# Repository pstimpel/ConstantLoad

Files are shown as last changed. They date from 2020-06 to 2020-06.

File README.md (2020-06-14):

# Adjustable Constant Load, Constant Current and Constant Power

Based on the work of GreatScott https://www.instructables.com/id/DIY-Adjustable-Constant-Load-Current-Power/

## Improvements compared to GreatScotts original version

* better handling of the rotary encoder
* the original project was a little bit dangerous. If the Arduino boots or resets during probing, the mosfet was fully open for about 2 seconds. A 10k resistor from PWM pin to ground solved this
* the glas fuse was replaced by a polyfuse, 0.9A
* added temperature control using a 1wire DS18B20 sensor. Includes shutdown of the whole device if temperature alarm was triggered
* added software based over current protection and over power protection in source code
* switched to INA219 sensor for measuring voltage and current, makes voltage divider and ACS712 obsolete. This sensor can handle up to 26V and 3.2A - however, we are using much lower values
* Added a 3d printed case to the repository. 
* Since we do not have to rely on the low resolution of the Arduino ADC anymore, we can measure both current and voltage with more precision and resolution.

IMAGE ALT TEXT HERE (https://www.youtube.com/watch?v=1KW89nFb7pY)

## BOM, tools used by me

* Arduino Nano
* INA219 breakout
* MicroUSB breakout (I am powering my 5V benchstuff using MicroUSB, this is not needed if you supply 5V in another way)
* Mosfet IRFZ44N
* Mosfet driver IC TC4420, maybe 2x4 IC socket as well?
* some 2.54mm pinheaders
* some wires
* Resistors, 0.25W: 10R, 4k7, 10k
* Electrolytic capacitors, 10V: 22uF, 470uF
* Polyfuse 0.9A
* LCD 16x2, I2C
* Rotary Encoder
* Dupont cables female female
* 2 binding posts 4mm
* 1 switch SPST
* 1 heatsink, big enough to deal with the heat
* 5V power supply
* M4 screws to mount temperatur sensor and mosfet to the heatsink
* Solder stuff
* some basic tools like a screw driver, alan keys and so on
* M3.5 drill and M4 tap and die tool to add holes into the heatsink of not there already
* M4.5 drill to widen the hole in the TO220 case of the mosfet.

You should be able to source all parts from your top supplier for parts. At the moment the bill represents a value of less than 50 Euros, given you own all the tools already.

If you are using the 3D printed case I am providing in subfolder stl

* M3 screws to mount the housing parts to each other
* M2 screws to fix the LCD in its place
* a 3D printer and some filament of your choice
 
## Home of this project

https://github.com/pstimpel/ConstantLoad

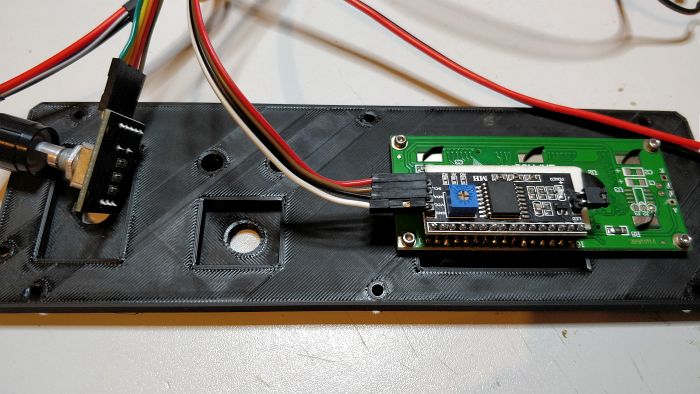
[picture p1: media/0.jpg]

 
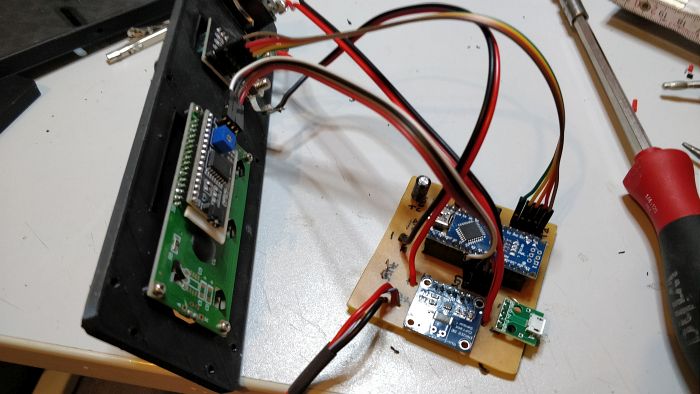
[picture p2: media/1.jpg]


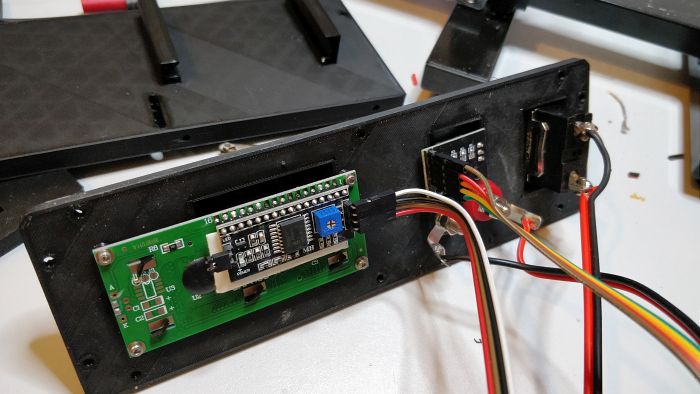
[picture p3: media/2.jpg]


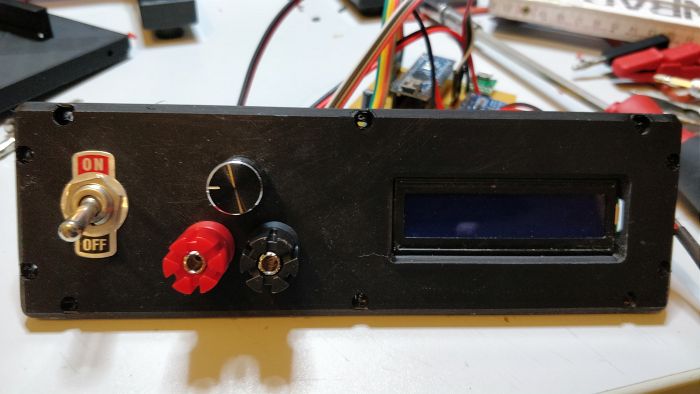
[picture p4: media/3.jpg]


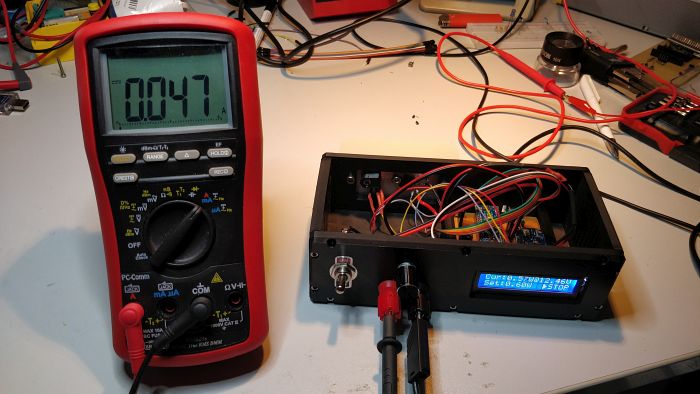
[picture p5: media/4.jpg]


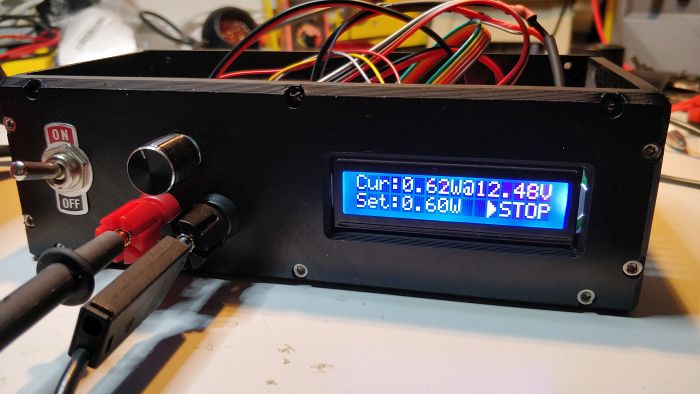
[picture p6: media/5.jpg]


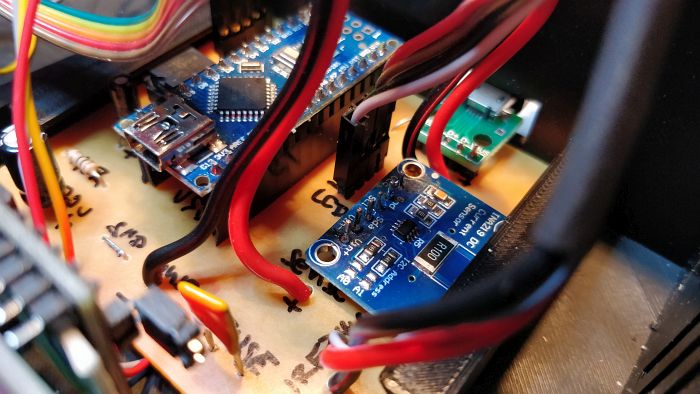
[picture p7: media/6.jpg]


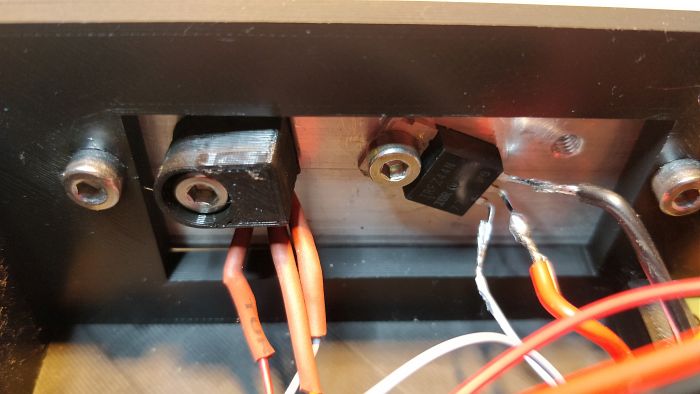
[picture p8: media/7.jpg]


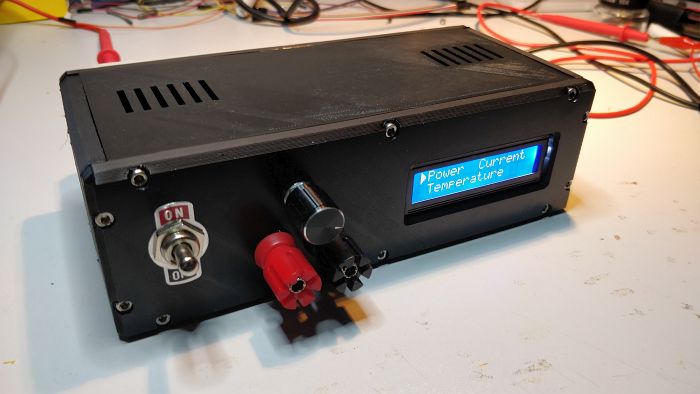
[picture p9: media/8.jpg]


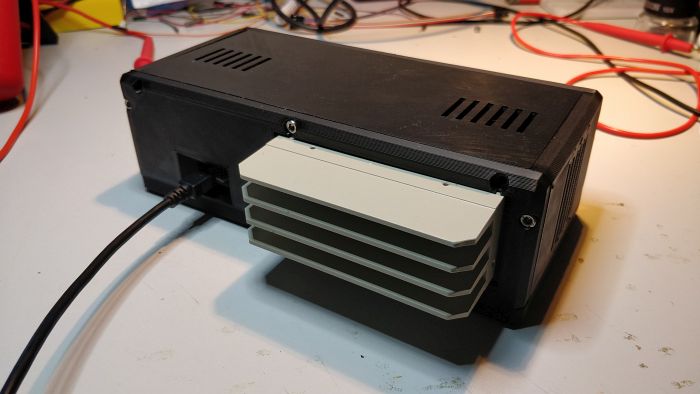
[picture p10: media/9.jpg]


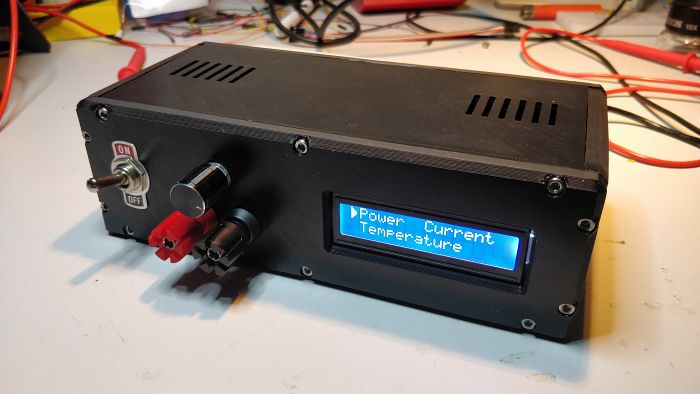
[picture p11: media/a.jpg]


## Build instructions

Just follow the guide by GreatScott. Different steps are:

1.) Use the circuit provided by me to take advantage of temperature control, some more security and the different sensor

2.) Use the Arduino sketch provided by me to take advantage of temperature control, some more security and the different sensor. On top you will find the use of this device a little bit easier. At least I do.

## 3D print instructions

There is nothing special. I used PLA, no supports needed. 3 shells and 10% infill did it. 

## Arduino Libraries

https://github.com/johnrickman/LiquidCrystal_I2C

https://github.com/adafruit/Adafruit_INA219

https://www.pjrc.com/teensy/td_libs_OneWire.html

https://github.com/milesburton/Arduino-Temperature-Control-Library

## How to use

Connect the device to 5V power source. Connect the circuit you want to "probe". Take care of plus and minus. Power the device on. Select the desired measuring method from the main menu. Current creates a constant current load, while Power creates a constant power load. Under Temperature you can monitor the temperature sensor and review the set temperature alarm threshold.

Once you select your Watts or Amperes and start the load mechanism, it might take a few seconds until the load starts consuming electrons. This is because the Arduino does probe step by step how much the mosfet should be open to turn the desired current into heat. This is a protection, do not attempt to speed up this process.

If one of the software protection measures was activated, the whole device will stop operation, including the mosfet. You have to turn off and on the device to restart operation. It is a good choice to clear the mistake that triggered the protection.

Since we use a polyfuse, the curcuit becomes cut once the fuse triggers due too much current. Just switch off the device and wait a few minutes so the fuse can cool down a bit. By cooling down, the fuse becomes operational again.

Be careful, the device does some overshooting once it tries to find the right mosfet balancing. This overshooting can cause quite "nice" spikes in the current consumption. Stay relaxed with raising your thresholds.

## Possible improvements

I would like to have a more smooth Rotary encoder use. It hops around sometimes. Maybe it is the cheap encoder I got, maybe there are better options to read the button press and encoder turns. 

I guess it is quite important to add more security features, like a working over voltage protection and over current protection based on hardware, not software. Right now we have over current protection and over power protection in software, only. Over voltage protection is not functional yet as well.

It should be possible to protect the device from wrong connected probing. If you turn around plus and minus of the circuit you want to put load on, strange things might happen. 

If the heatsink gets too hot, I would like to add a fan and some fan control, so the fan mounted to the heatsink could kick in and help with the cooling. We have plenty of options since we have our Arduino in the middle of our device. 

## Thanks to ...

GreatScott. His Youtube channel provides lots of insights and many cool projects. You should pay him a visit.

## Feedback

If you go for a build, I would like it very much to hear from you. Maybe you want to share pics of your device? You can find me at

https://twitter.com/PjotrS72

https://www.prusaprinters.org/social/2411-pstimpel/prints

https://www.thingiverse.com/pstimpel

## Finally...

I am providing this stuff as it is. I do not promise anything, and I am not responsible for any harm you might create or receive by following this manual or by using the methods and results described in this manual.

### Warning

High current / power can cause heat, and heat can cause injuries. Make sure you adapt the warnlevels on top of the Arduino sketch to your needs. Especially the temperature alarm threshold should be set below the melting temperature of your filament if you were going for the 3D printed case.

## License: 

https://creativecommons.org/licenses/by-nc-sa/4.0/

Most obvious limits of this license:
* You are not allowed to use this stuff for commercial purposes
* You can download, reupload and change the stuff, but have to release it under the same license again
* You have the mention the origin, like "Original by Peter Stimpel, https://github.com/pstimpel/ConstantLoad"

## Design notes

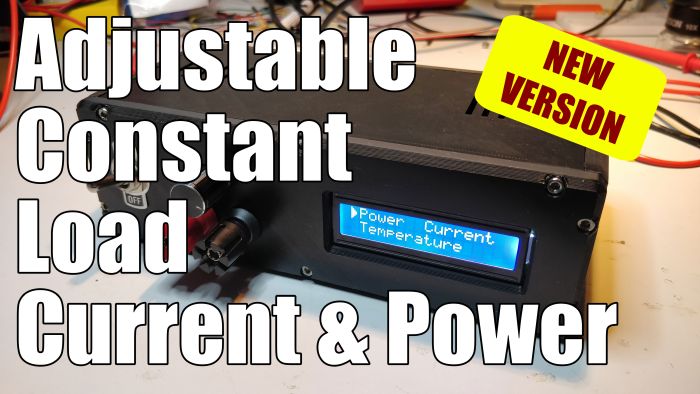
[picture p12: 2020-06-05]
media/title_16_9sm.jpg

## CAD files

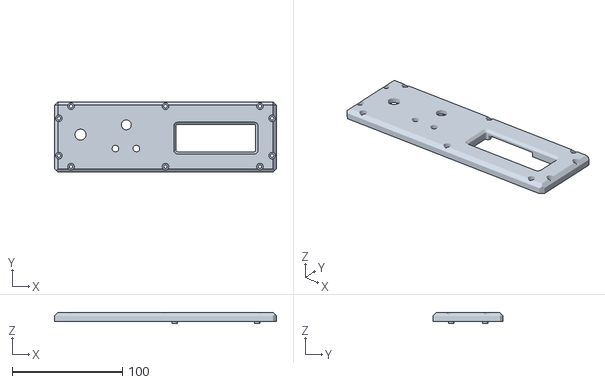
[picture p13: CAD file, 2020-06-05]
stl/Front.stl
201.5 x 63.8 x 10.0

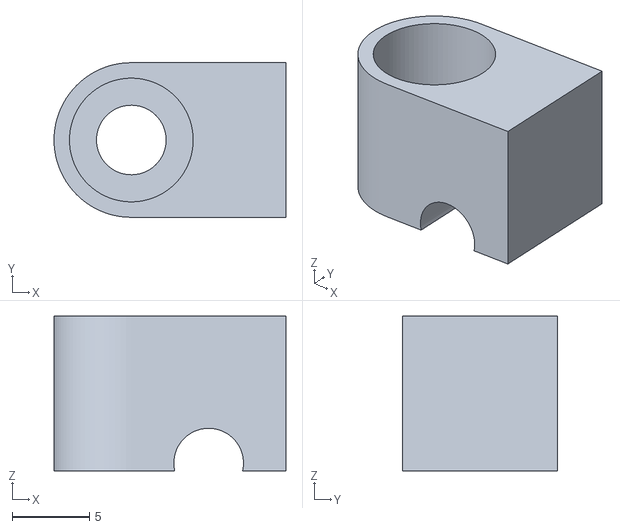
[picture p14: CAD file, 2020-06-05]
stl/Heatsensorclamp.stl
15.0 x 10.0 x 10.0

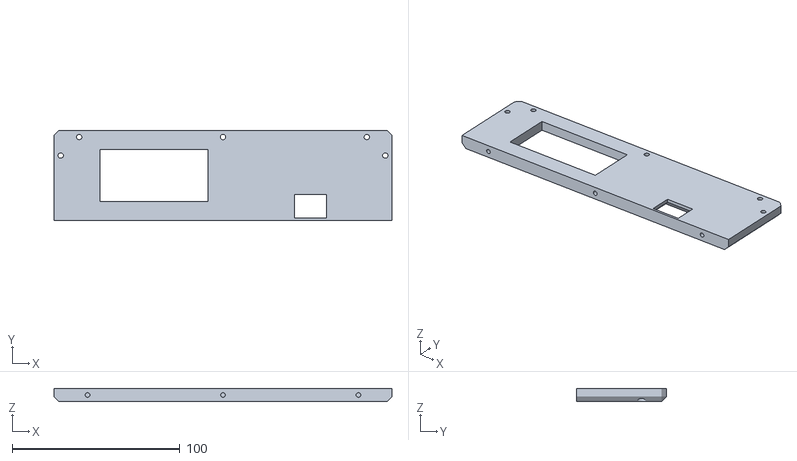
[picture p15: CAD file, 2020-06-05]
stl/Back.stl
201.5 x 53.8 x 8.00

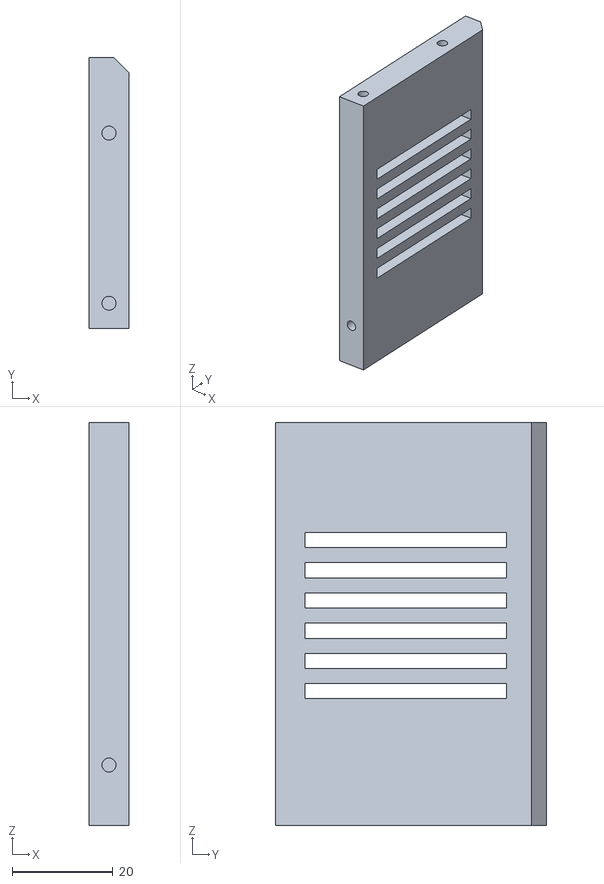
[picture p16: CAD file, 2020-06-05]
stl/Right.stl
8.00 x 53.8 x 80.0

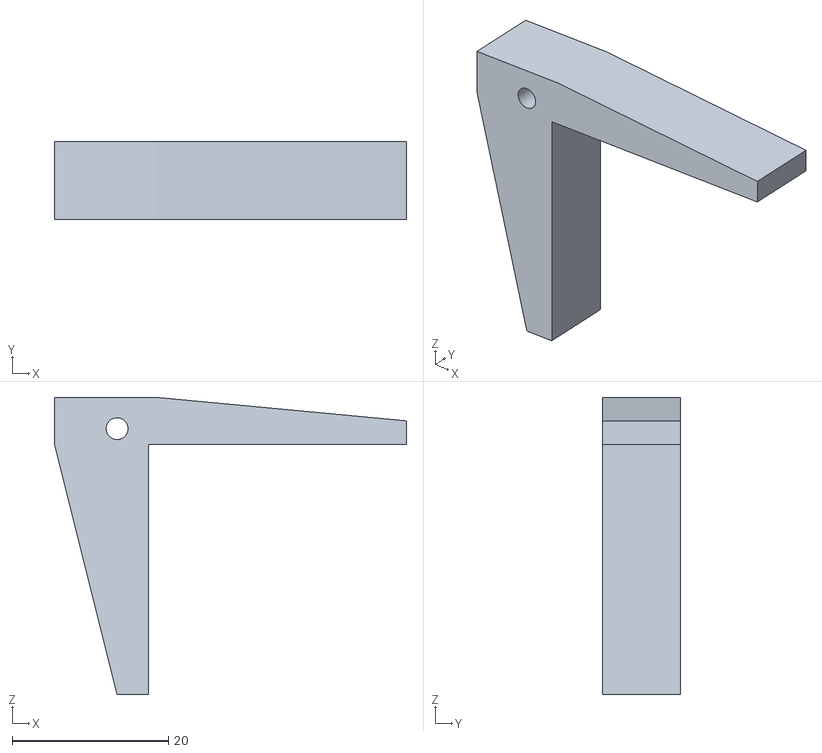
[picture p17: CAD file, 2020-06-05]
stl/PCBLock.stl
45.0 x 10.0 x 38.0

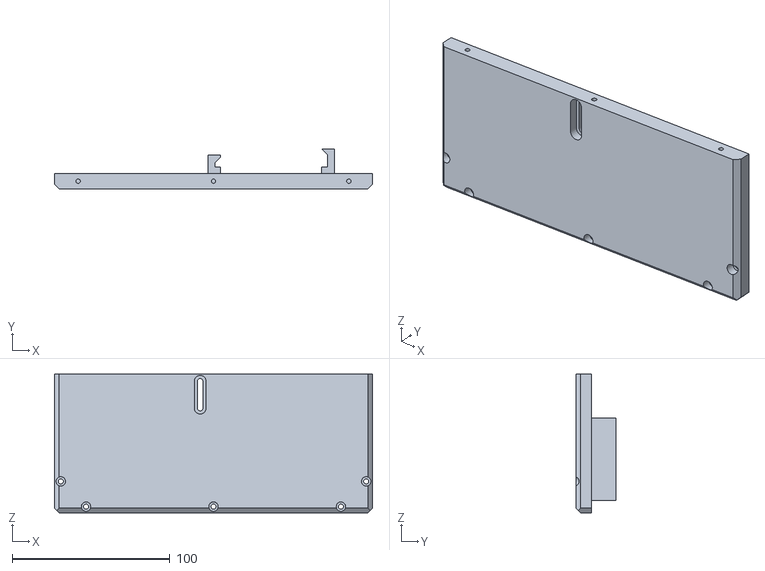
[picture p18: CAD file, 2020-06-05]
stl/Bottom.stl
201.5 x 25.4 x 88.0

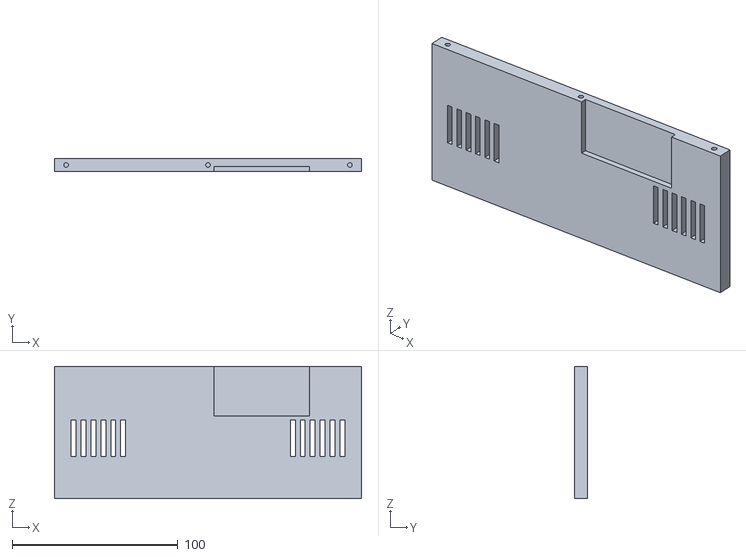
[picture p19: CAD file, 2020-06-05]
stl/Top.stl
185.5 x 8.00 x 80.0

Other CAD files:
stl/Left.stl

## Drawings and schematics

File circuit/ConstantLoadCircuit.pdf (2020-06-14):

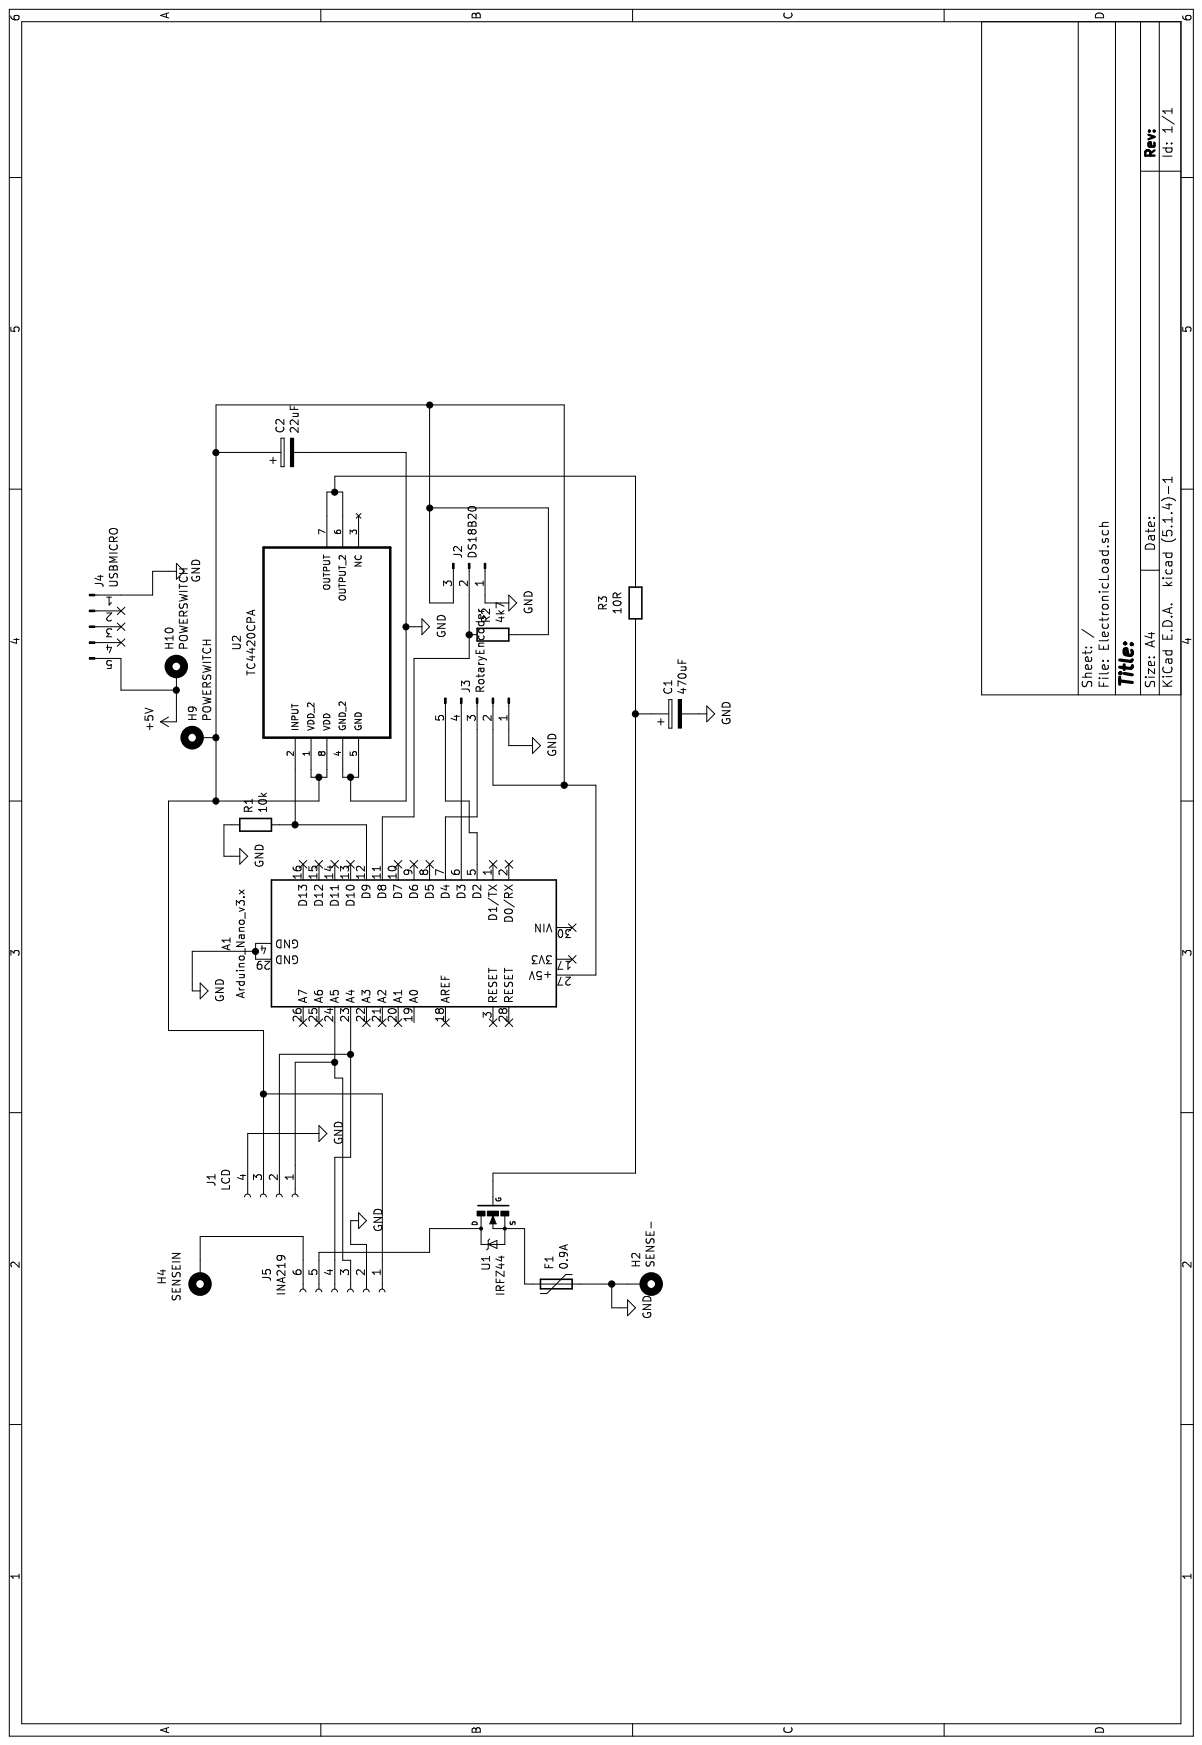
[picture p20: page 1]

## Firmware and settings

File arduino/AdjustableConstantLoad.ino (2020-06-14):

float temperaturealarm = 50.0; //Switch Mosfet PWM down if higher than "temperaturealarm °C"
float voltagealarm = 25.0; //Switch Mosfet PWM down if higher than "voltage V", voltage alarm is not functional yet, but we need the value for limiting the power setting as well
float currentalarm = 0.90; //Switch Mosfet PWM down if higher than "current A"
float voltageMin = 0.005; //do not raise PWM if voltage lower than "voltageMin V"

float poweralarm = voltagealarm * currentalarm;

#include <Wire.h>
#include <LiquidCrystal_I2C.h>
#include <Adafruit_INA219.h>
#include <OneWire.h>
#include <DallasTemperature.h>

LiquidCrystal_I2C lcd(0x27, 16, 2);
Adafruit_INA219 ina219;

#define ONE_WIRE_BUS 8

OneWire oneWire(ONE_WIRE_BUS);
DallasTemperature sensors(&oneWire);


#define clk 2
#define dt 3
#define sw 4
#define pwm 9
#define currentsense A0
#define voltagesense A2
char screen = 0;
char arrowpos = 0;
float power = 0;
float current = 0;

int currentStateCLK;
int previousStateCLK;
int counter = 0;
volatile int virtualPosition = 50;
volatile int lastCount = 50;
volatile boolean currentmode = false;

volatile boolean powermode = false;
volatile boolean temperaturemode = false;
volatile boolean TurnDetected = false;
volatile boolean up = false;
volatile boolean button = false;
const unsigned char PS_128 = (1 << ADPS2) | (1 << ADPS1) | (1 << ADPS0);
volatile  float shuntvoltage = 0;
volatile  float busvoltage = 0;
volatile  float current_mA = 0;
volatile  float current_A = 0;
volatile  float loadvoltage_V = 0;
volatile  float power_mW = 0;
volatile  float power_W = 0;

volatile float temperature = -999.0;
volatile int temperaturecounter = 0;

volatile float wattarray[5] = {0.0, 0.0, 0.0, 0.0, 0.0};
volatile float voltarray[5] = {0.0, 0.0, 0.0, 0.0, 0.0};
volatile float amparray[5] = {0.0, 0.0, 0.0, 0.0, 0.0};

volatile bool allowignore = true;

byte customChar1[8] = {
  0b10000,
  0b11000,
  0b11100,
  0b11110,
  0b11110,
  0b11100,
  0b11000,
  0b10000
};

byte customChar2[8] = {
  0b00100,
  0b01110,
  0b11111,
  0b00000,
  0b00000,
  0b11111,
  0b01110,
  0b00100,
};

byte customChar3[8] = {
  0b00010,
  0b00110,
  0b01110,
  0b11110,
  0b11110,
  0b01110,
  0b00110,
  0b00010,
};

ISR(PCINT2_vect) {
  if (digitalRead(sw) == LOW) {
    button = true;
  }
}

void isrturn ()  {
  static unsigned long lastInterruptTime = 0;
  unsigned long interruptTime = millis();

  if (interruptTime - lastInterruptTime > 3) {
    if (digitalRead(dt) == LOW)
    {
      virtualPosition++ ; // Could be -5 or -10
    }
    else {
      virtualPosition-- ; // Could be +5 or +10
    }
  }
  lastInterruptTime = interruptTime;
}

void setup() {
  pinMode(pwm, OUTPUT);
  digitalWrite(pwm, LOW);

  Serial.begin(115200);
  pinMode(sw, INPUT_PULLUP);
  pinMode(clk, INPUT);
  pinMode(dt, INPUT);
  pinMode(currentsense, INPUT);

  ADCSRA &= ~PS_128;
  ADCSRA |= (1 << ADPS1) | (1 << ADPS0);
  PCICR |= 0b00000100;
  PCMSK2 |= 0b00010000;   // turn o PCINT20(D4)
  attachInterrupt(digitalPinToInterrupt(clk), isrturn, LOW);
  Wire.begin();
  previousStateCLK = digitalRead(clk);

  TCCR1A = 0;
  TCCR1A = (1 << COM1A1) | (1 << WGM11);
  TCCR1B = 0;
  TCCR1B = (1 << WGM13) | (1 << WGM12) | (1 << CS10);
  ICR1 = 2047;
  OCR1A = 0;
  Serial.println("Init Display");

  lcd.init();
  lcd.backlight();
  lcd.createChar(0, customChar1);
  lcd.createChar(1, customChar2);
  lcd.createChar(2, customChar3);
  lcd.clear();

  Serial.println("Display done");
  Serial.println("Init 1Wire");
  sensors.begin();
  Serial.println("1Wire done");
  Serial.println("Init INA219");

  if (! ina219.begin()) {
    lcd.print(" Sensor failed");

    while (1) {
      delay(10);
    }

  }
  ina219.setCalibration_32V_1A();
  
  Serial.println("INA219 done");
  lcd.print(" ADJ CONST LOAD");
  lcd.setCursor(0, 1);
  lcd.print("ENHANCED VERSION");

  delay(1000);
  screen0();
  lcd.setCursor(0, 0);
  lcd.write((uint8_t)0);
  Serial.println("Setup done");
}

void loop() {
  delayMicroseconds(1000);

  shuntvoltage = ina219.getShuntVoltage_mV();
  busvoltage = ina219.getBusVoltage_V();
  current_mA = ina219.getCurrent_mA();
  //power_mW = ina219.getPower_mW();
  //power_W = power_mW / 1000.0;
  current_A = current_mA / 1000.0;

  bool zeroedvales=false;
  loadvoltage_V = busvoltage + (shuntvoltage / 1000);
  if (loadvoltage_V < 0.0 || current_A < 0.0) {
    /*
    Serial.print("zeroing values ");
    Serial.print(loadvoltage_V);
    Serial.print(" V ");
    Serial.print(current_A);
    Serial.println(" A");
    */
    loadvoltage_V = 0.0;
    current_A = 0.0;
    zeroedvales = true;
    
  }
  //if (shuntvoltage < 0.05) {
  //  loadvoltage_V = 0.0;
  //  Serial.println("zeroing shuntvoltage");
  //}
  /*
  Serial.print("A ");
  Serial.print(current_A);
  Serial.print(" V ");
  Serial.print(loadvoltage_V);
  Serial.print(" W ");
  Serial.print(power_W);
  */
  power_W = loadvoltage_V * current_A;

  bool doprocess=true;
  
  if(zeroedvales == true && allowignore == true) {
    allowignore = false;
    doprocess = false;
    //Serial.print(" forced ignore ");
  } else if (zeroedvales == false) {
    allowignore=true;
  }

  if(doprocess == true) {
    
    //build averages
    wattarray[0] = wattarray[1];
    wattarray[1] = wattarray[2];
    wattarray[2] = wattarray[3];
    wattarray[3] = wattarray[4];
    wattarray[4] = power_W;
  
    power_W = (wattarray[0] + wattarray[1] + wattarray[2] + wattarray[3] + wattarray[4]) / 5;
  
    voltarray[0] = voltarray[1];
    voltarray[1] = voltarray[2];
    voltarray[2] = voltarray[3];
    voltarray[3] = voltarray[4];
    voltarray[4] = loadvoltage_V;
  
    loadvoltage_V = (voltarray[0] + voltarray[1] + voltarray[2] + voltarray[3] + voltarray[4]) / 5;
  
    amparray[0] = amparray[1];
    amparray[1] = amparray[2];
    amparray[2] = amparray[3];
    amparray[3] = amparray[4];
    amparray[4] = current_A;
  
    current_A = (amparray[0] + amparray[1] + amparray[2] + amparray[3] + amparray[4]) / 5;
    /*
    Serial.print(" As ");
    Serial.print(current_A);
    Serial.print(" Vs ");
    Serial.print(loadvoltage_V);
    Serial.print(" Ws ");
    Serial.println(power_W);
    */
  }

  temperaturecounter++;
  if (screen != 7 && screen != 6 && screen != 3) {
    if (temperaturecounter == 100) {
      lcd.setCursor(15, 1);
      lcd.print(".");
    } else if (temperaturecounter == 200) {
      lcd.setCursor(15, 1);
      lcd.print(" ");
    }
  }
  if (temperaturecounter > 200) {
    sensors.requestTemperatures();
    temperature = sensors.getTempCByIndex(0);
    temperaturecounter = 0;
    /*
      Serial.print("C ");
      Serial.println(temperature);
      Serial.print("A ");
      Serial.println(current_A);
      Serial.print("V ");
      Serial.println(loadvoltage_V);
      Serial.print("SV ");
      Serial.println((shuntvoltage / 1000));
      Serial.print("BV ");
      Serial.println(busvoltage);
      Serial.print("W ");
      Serial.println(power_W);
      Serial.print("OCR1A ");
      Serial.println(OCR1A);
    */
  }




  if ((currentalarm < current_A && loadvoltage_V > 0.05) || currentalarm < current_A) {
    OCR1A = 0;
    screen10();
    screen = 10;
    Serial.print("ocr1a ");
    Serial.println(OCR1A);
    Serial.println("Operation stopped due current, waiting for switch off");
    while (1) {
      delay(10);
    }
  }
  /*
    if ((voltagealarm < loadvoltage_V && current_A > 0.2) || 26.0 < loadvoltage_V) {
    OCR1A = 0;
    screen9();
    screen = 9;
    Serial.print("ocr1a ");
    Serial.println(OCR1A);
    Serial.println("Operation stopped due voltage, waiting for switch off");
    while (1) {
      delay(10);
    }
    }
  */
  if (temperaturealarm < temperature) {
    OCR1A = 0;
    screen8();
    screen = 8;
    Serial.print("ocr1a ");
    Serial.println(OCR1A);
    Serial.println("Operation stopped due temperature, waiting for switch off");
    while (1) {
      delay(10);
    }
  }

  if (temperaturemode) {
    if (counter == 200) {
      lcd.setCursor(6, 0);
      lcd.print(temperature);
      lcd.print("C   ");
      counter = 0;
    }
    counter++;
  }

  if (currentmode) {
    /*
      Serial.print("A  ");
      Serial.println(current_A);
      Serial.print("V  ");
      Serial.println(loadvoltage_V);
      Serial.print("W  ");
      Serial.println(power_W);
    */
    if (counter == 100) {
      lcd.setCursor(4, 0);
      lcd.print(current_A);
      lcd.print("A@");
      lcd.print(loadvoltage_V);
      lcd.print("V");
      counter = 0;
    }
    if (current_A < current && loadvoltage_V > voltageMin) {
      if(current_A < 0.1 && OCR1A < 2000) {
        OCR1A = OCR1A + 10;
      } else {
        OCR1A = OCR1A + 1;
      }
    }
    else {
      if (OCR1A > 0) {
        OCR1A = OCR1A - 1;
      }
    }
    if (OCR1A < 0) {
      OCR1A = 0;
    }
    Serial.print("ocr1a ");
    Serial.println(OCR1A);
    counter++;
    delayMicroseconds(100);
  }

  if (powermode) {
    /*
        Serial.print("A  ");
        Serial.println(current_A);
        Serial.print("V  ");
        Serial.println(loadvoltage_V);
        Serial.print("W  ");
        Serial.println(power_W);
    */
    if (counter == 100) {
      lcd.setCursor(4, 0);
      lcd.print(power_W);
      lcd.print("W@");
      lcd.print(loadvoltage_V);
      lcd.print("V");
      counter = 0;
    }
    if (power_W < power && loadvoltage_V > voltageMin) {
      if(power_W < 0.1 && OCR1A < 2000) {
        OCR1A = OCR1A + 10;
      } else {
        OCR1A = OCR1A + 1;
      }
    }
    else {
      if (OCR1A > 0) {
        OCR1A = OCR1A - 1;
      } else {
        OCR1A = 0;
      }
    }
    if (OCR1A < 0) {
      OCR1A = 0;
    }
    Serial.print("ocr1a ");
    Serial.println(OCR1A);
    counter++;
    delayMicroseconds(100);
  }

  if (virtualPosition != lastCount) {

    if (virtualPosition > lastCount) {
      //UP
      TurnDetected = true;
      up = true;
    } else {
      //DOWN
      TurnDetected = true;
      up = false;
    }

    lastCount = virtualPosition ;

  }

  if (TurnDetected) {
    //delay(50);
    switch (screen) {
      case 0:
        switch (arrowpos) {
          case 0:
            if (!up) {
              screen0();
              lcd.setCursor(7, 0);
              lcd.write((uint8_t)0);
              arrowpos = 1;
            }
            break;
          case 1:
            if (!up) {
              screen0();
              lcd.setCursor(0, 1);
              lcd.write((uint8_t)0);
              arrowpos = 2;
            } else {
              screen0();
              lcd.setCursor(0, 0);
              lcd.write((uint8_t)0);
              arrowpos = 0;
            }
            break;
          case 2:
            if (up) {
              screen0();
              lcd.setCursor(7, 0);
              lcd.write((uint8_t)0);
              arrowpos = 1;
            }
            break;
        }
        break;
      case 1:
        switch (arrowpos) {
          case 0:
            if (!up) {
              screen1();
              lcd.setCursor(0, 1);
              lcd.write((uint8_t)0);
              arrowpos = 1;
            }
            break;
          case 1:
            if (up) {
              screen1();
              lcd.setCursor(0, 0);
              lcd.write((uint8_t)0);
              arrowpos = 0;
            }
            else {
              screen1();
              lcd.setCursor(7, 1);
              lcd.write((uint8_t)0);
              arrowpos = 2;
            }
            break;
          case 2:
            if (up) {
              screen1();
              lcd.setCursor(0, 1);
              lcd.write((uint8_t)0);
              arrowpos = 1;
            }
            break;
        }
        break;
      case 2:
        if (up) {
          power = power - 0.1;
          if (power < 0) {
            power = 0;
          }
          lcd.setCursor(7, 0);

          lcd.print(power);
          lcd.print("W");
          lcd.write((uint8_t)1);
          lcd.print("  ");
        }
        else {
          power = power + 0.1;
          if (power > poweralarm) {
            power = poweralarm;
          }
          lcd.setCursor(7, 0);

          lcd.print(power);
          lcd.print("W");
          lcd.write((uint8_t)1);
          lcd.print("  ");
        }
        break;
      case 4:
        switch (arrowpos) {
          case 0:
            if (!up) {
              screen4();
              lcd.setCursor(0, 1);
              lcd.write((uint8_t)0);
              arrowpos = 1;
            }
            break;
          case 1:
            if (up) {
              screen4();
              lcd.setCursor(0, 0);
              lcd.write((uint8_t)0);
              arrowpos = 0;
            }
            else {
              screen4();
              lcd.setCursor(7, 1);
              lcd.write((uint8_t)0);
              arrowpos = 2;
            }
            break;
          case 2:
            if (up) {
              screen4();
              lcd.setCursor(0, 1);
              lcd.write((uint8_t)0);
              arrowpos = 1;
            }
            break;
        }
        break;
      case 5:
        if (up) {
          current = current - 0.05;
          if (current < 0) {
            current = 0;
          }
          lcd.setCursor(9, 0);
          lcd.print(current);
          lcd.print("A");
          lcd.write((uint8_t)1);
          lcd.print(" ");
        }
        else {
          current = current + 0.05;
          if (current > currentalarm) {
            current = currentalarm;
          }
          lcd.setCursor(9, 0);
          lcd.print(current);
          lcd.print("A");
          lcd.write((uint8_t)1);
          lcd.print(" ");
        }
        break;
    }
    TurnDetected = false;

  }

  if (button) {
    delay(100);
    switch (screen) {
      case 0:
        if (arrowpos == 0) {
          screen = 1;
          screen1();
          lcd.setCursor(0, 0);
          lcd.write((uint8_t)0);
        } else if (arrowpos == 1) {
          screen = 4;
          screen4();
          lcd.setCursor(0, 0);
          lcd.write((uint8_t)0);
        }
        else {
          temperaturemode = true;
          screen = 7;
          screen7();
          lcd.setCursor(11, 1);
          lcd.write((uint8_t)0);
        }
        break;
      case 1:
        switch (arrowpos) {
          case 0:
            screen = 2;
            screen2();
            break;
          case 1:
            if (power > 0.0) {
              powermode = true;
              OCR1A = 0;
              screen = 3;
              screen3();
            } else {

              screen = 2;
              screen2();
            }
            break;
          case 2:
            screen = 0;
            screen0();
            lcd.setCursor(0, 0);
            lcd.write((uint8_t)0);
            break;
        }
        break;
      case 2:
        screen = 1;
        screen1();
        lcd.setCursor(0, 0);
        lcd.write((uint8_t)0);
        break;
      case 3:
        powermode = false;
        OCR1A = 0;
        counter = 0;
        screen = 1;
        screen1();
        lcd.setCursor(0, 0);
        lcd.write((uint8_t)0);
        break;
      case 4:
        switch (arrowpos) {
          case 0:
            screen = 5;
            screen5();
            break;
          case 1:
            if (current > 0.0) {
              OCR1A = 0;
              screen = 6;
              screen6();
              currentmode = true;
              counter = 0;
            } else {
              screen = 5;
              screen5();

            }
            break;
          case 2:
            screen = 0;
            screen0();
            lcd.setCursor(0, 0);
            lcd.write((uint8_t)0);
            break;
        }
        break;
      case 5:
        screen = 4;
        screen4();
        lcd.setCursor(0, 0);
        lcd.write((uint8_t)0);
        break;
      case 6:
        screen = 4;
        screen4();
        lcd.setCursor(0, 0);
        lcd.write((uint8_t)0);
        currentmode = false;
        OCR1A = 0;
        break;
      case 7:
        temperaturemode = false;
        screen = 0;
        screen0();
        lcd.setCursor(0, 0);
        lcd.write((uint8_t)0);
        break;
    }
    arrowpos = 0;
    button = false;
  }
}

void screen0() {
  lcd.clear();
  lcd.setCursor(1, 0);
  lcd.print("Power  ");
  lcd.print("Current");
  lcd.setCursor(1, 1);
  lcd.print("Temperature");

}

void screen1() {
  lcd.clear();
  lcd.setCursor(1, 0);
  lcd.print("Power:");
  lcd.print(power);
  lcd.print("W");
  lcd.setCursor(1, 1);
  lcd.print("Start");
  lcd.setCursor(8, 1);
  lcd.print("Back");
}

void screen2() {
  lcd.clear();
  lcd.setCursor(0, 0);
  lcd.write((uint8_t)2);
  lcd.print("Power:");
  lcd.print(power);
  lcd.print("W");
  lcd.write((uint8_t)1);
}

void screen3() {
  lcd.clear();
  lcd.print("Cur:");
  lcd.print(power_W);
  lcd.print("W");
  lcd.setCursor(0, 1);
  lcd.print("Set:");
  lcd.print(power);
  lcd.print("W");
  lcd.setCursor(11, 1);
  lcd.write((uint8_t)0);
  lcd.print("STOP");
}

void screen4() {
  lcd.clear();
  lcd.setCursor(1, 0);
  lcd.print("Current:");
  lcd.print(current);
  lcd.print("A");
  lcd.setCursor(1, 1);
  lcd.print("Start");
  lcd.setCursor(8, 1);
  lcd.print("Back");
}

void screen5() {
  lcd.clear();
  lcd.setCursor(0, 0);
  lcd.write((uint8_t)2);
  lcd.print("Current:");
  lcd.print(current);
  lcd.print("A");
  lcd.write((uint8_t)1);
}

void screen6() {
  lcd.clear();
  lcd.print("Cur:");
  lcd.print(current_A);
  lcd.print("A");
  lcd.setCursor(0, 1);
  lcd.print("Set:");
  lcd.print(current);
  lcd.print("A");
  lcd.setCursor(11, 1);
  lcd.write((uint8_t)0);
  lcd.print("STOP");
}

void screen7() {
  lcd.clear();
  lcd.print("Temp: ");
  lcd.print(temperature);
  lcd.print("C");
  lcd.setCursor(0, 1);
  lcd.print("< ");
  lcd.print(temperaturealarm);
  lcd.print("C");
  lcd.setCursor(11, 1);
  lcd.write((uint8_t)0);
  lcd.print("Back");
}

void screen8() {
  lcd.clear();
  lcd.print("!! TEMP ALARM !! ");
  lcd.setCursor(0, 1);
  lcd.print("Shutdown! ");
  lcd.print(temperature);
  lcd.print("C");

}

void screen9() {
  lcd.clear();
  lcd.print("OV Warn ");
  lcd.print(OCR1A);
  lcd.setCursor(0, 1);
  lcd.print("Shutdown! ");
  lcd.print(loadvoltage_V);
  lcd.print("V");

}

void screen10() {
  lcd.clear();
  lcd.print("OC Warn ");
  lcd.print(OCR1A);
  lcd.setCursor(0, 1);
  lcd.print("Shutdown! ");
  lcd.print(current_A);
  lcd.print("A");

}

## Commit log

2020-06-05 Limit possible power and current to the set alarms, and disable the over voltage protection, finally. This needs a better solution like debouncing the sensor values a little.
2020-06-14 Tackle odd sensorreadings
    Limit the stuff to 0.9A, change the Fuse to 0.9A, change the sensor resolution to 1A range, create smoother sensorvalues by creating averages, jumpstart by allowing bigger raise of pulse on really lo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
2020-06-14 Updated circuit to meet the 0.9A fuse
